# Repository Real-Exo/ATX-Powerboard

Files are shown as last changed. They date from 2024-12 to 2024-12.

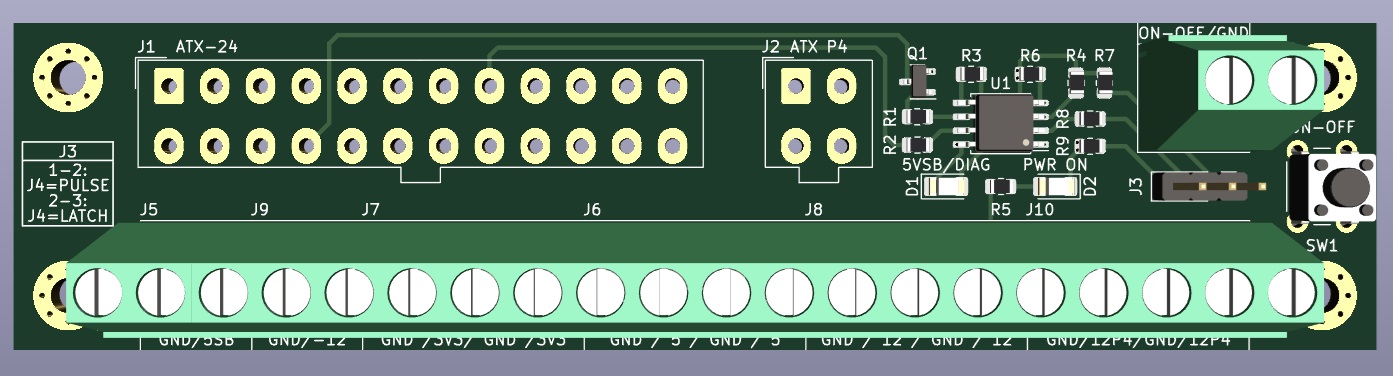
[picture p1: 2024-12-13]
ATX Powerboard/3D Render/ATX Powerboard.jpg

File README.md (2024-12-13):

A small board that allows controlling a standard ATX PC power supply in order to power other things. 
Onboard ON/OFF switch. External ON/OFF can be configured to be pulsed (push-button, for example) or latching (switch).
Do not change configuration jumper while board is running as that triggers a safety lockup (flashing diag LED).
Monitors PSU power good signal and turns PSU off when PWR_GOOD is not asserted, flashing diag LED.

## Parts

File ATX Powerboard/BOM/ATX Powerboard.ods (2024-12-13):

# | Reference | Qty | Value | Footprint | DNP | Partcode
1 | C1 | 1 | 100n | Capacitor_SMD:C_0805_2012Metric |  | CL21B104KBCNFNC
2 | D1, D2 | 2 | LED_Small | LED_SMD:LED_1206_3216Metric |  | 1206 SMD LED of choice, low current/high brightness
3 | J1 | 1 | ATX-24 | Connector_Molex:Molex_Mini-Fit_Jr_5566-24A_2x12_P4.20mm_Vertical |  | 39-28-1243 Molex
4 | J2 | 1 | ATX P4 | Connector_Molex:Molex_Mini-Fit_Jr_5566-04A_2x02_P4.20mm_Vertical |  | 39-28-1043 Molex
5 | J3 | 1 | M/L | Connector_PinHeader_2.54mm:PinHeader_1x03_P2.54mm_Vertical |  | Standard 2.54mm pin header
6 | J4 | 1 | ON/OFF | TerminalBlock_Phoenix:TerminalBlock_Phoenix_MKDS-1,5-2-5.08_1x02_P5.08mm_Horizontal |  | 1711767
7 | J5 | 1 | +5V STDBY | TerminalBlock_Phoenix:TerminalBlock_Phoenix_MKDS-1,5-2-5.08_1x02_P5.08mm_Horizontal |  | 1711767
8 | J6 | 1 | +5V | TerminalBlock_Phoenix:TerminalBlock_Phoenix_MKDS-1,5-4-5.08_1x04_P5.08mm_Horizontal |  | 2x 1711767
9 | J7 | 1 | +3V3 | TerminalBlock_Phoenix:TerminalBlock_Phoenix_MKDS-1,5-4-5.08_1x04_P5.08mm_Horizontal |  | 2x 1711767
10 | J8 | 1 | +12V | TerminalBlock_Phoenix:TerminalBlock_Phoenix_MKDS-1,5-4-5.08_1x04_P5.08mm_Horizontal |  | 2x 1711767
11 | J9 | 1 | -12V | TerminalBlock_Phoenix:TerminalBlock_Phoenix_MKDS-1,5-2-5.08_1x02_P5.08mm_Horizontal |  | 1711767
12 | J10 | 1 | +12V P4 | TerminalBlock_Phoenix:TerminalBlock_Phoenix_MKDS-1,5-4-5.08_1x04_P5.08mm_Horizontal |  | 2x 1711767
13 | Q1 | 1 | BSS138 | Package_TO_SOT_SMD:SOT-23 |  | BSS138
14 | R1, R2, R4, R5, R6, R7, R8, R9 | 8 | 10K | Resistor_SMD:R_0805_2012Metric |  | RK73B2ATTD103J
15 | R3 | 1 | 3K3 | Resistor_SMD:R_0805_2012Metric |  | RK73B2ATTD332J
16 | SW1 | 1 | ON/OFF | Button_Switch_THT:SW_PUSH_6mm_H5mm |  | PTS645SL502LFS
17 | U1 | 1 | PIC12C508A-ISM | Package_SO:SOIC-8_5.275x5.275mm_P1.27mm |  | PIC12C508A-04/SM

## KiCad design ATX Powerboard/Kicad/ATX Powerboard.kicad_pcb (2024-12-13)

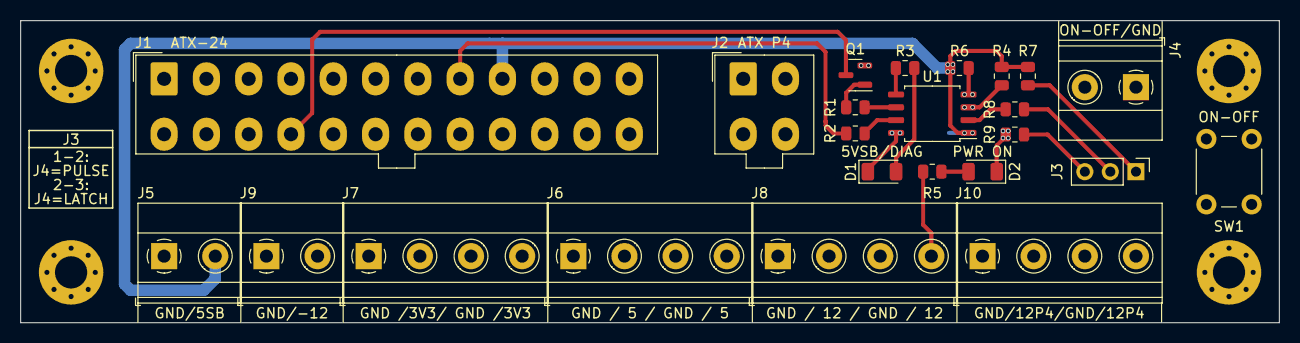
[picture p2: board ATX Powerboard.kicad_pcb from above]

Board: 4 copper layers, 125.0 x 30.0 mm, 25 parts (1 on the bottom side), 21 nets.

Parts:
C1: 100n; C_0805_2012Metric
D1: 5VSB/DIAG; LED_1206_3216Metric
D2: PWR ON; LED_1206_3216Metric
J1: ATX-24; Molex_Mini-Fit_Jr_5566-24A_2x12_P4.20mm_Vertical
J2: ATX P4; Molex_Mini-Fit_Jr_5566-04A_2x02_P4.20mm_Vertical
J3: M/L; PinHeader_1x03_P2.54mm_Vertical
J4: ON-OFF/GND; TerminalBlock_Phoenix_MKDS-1,5-2-5.08_1x02_P5.08mm_Horizont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
J5: GND/5SB; TerminalBlock_Phoenix_MKDS-1,5-2-5.08_1x02_P5.08mm_Horizont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
J6: GND / 5 / GND / 5; TerminalBlock_Phoenix_MKDS-1,5-4-5.08_1x04_P5.08mm_Horizont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
J7: GND /3V3/ GND /3V3; TerminalBlock_Phoenix_MKDS-1,5-4-5.08_1x04_P5.08mm_Horizont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
J8: GND / 12 / GND / 12; TerminalBlock_Phoenix_MKDS-1,5-4-5.08_1x04_P5.08mm_Horizont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
J9: GND/-12; TerminalBlock_Phoenix_MKDS-1,5-2-5.08_1x02_P5.08mm_Horizont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
J10: GND/12P4/GND/12P4; TerminalBlock_Phoenix_MKDS-1,5-4-5.08_1x04_P5.08mm_Horizont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
Q1: BSS138; SOT-23
R1, R2, R4, R5, R6, R7, R8, R9: 10K; R_0805_2012Metric
R3: 3K3; R_0805_2012Metric
SW1: ON-OFF; SW_PUSH_6mm_H5mm
U1: PIC12C508A-ISM; SOIC-8_5.275x5.275mm_P1.27mm

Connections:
+3V3: J1.1 (+3.3V), J1.2 (+3.3V), J1.12 (+3.3V), J1.13 (+3.3V), J7.2, J7.4
+5V: J1.4 (+5V), J1.6 (+5V), J1.21 (+5V), J1.22 (+5V), J1.23 (+5V), J6.2, J6.4
+5V STDBY: C1.1, J1.9 (+5VSB), J5.2, R4.1, R6.1, R7.1, U1.1 (VDD)
+12P: J2.3, J2.4, J10.2, J10.4
+12V: J1.10 (+12V), J1.11 (+12V), J8.2, J8.4, R5.1
-12V: J1.14 (-12V), J9.2
GND: C1.2, D1.1 (K), D2.1 (K), J1.3 (GND), J1.5 (GND), J1.7 (GND), J1.15 (GND), J1.17 (GND), J1.18 (GND), J1.19 (GND), J1.24 (GND), J2.1, J2.2, J4.1, J5.1, J6.1, J6.3, J7.1, J7.3, J8.1, J8.3, J9.1, J10.1, J10.3, Q1.2 (S), R9.1, SW1.2, U1.8 (VSS)
M/L: R8.1, U1.2 (GP5)
unnamed: D1.2 (A), R3.2
unnamed: D2.2 (A), R5.2
unnamed: J1.16 (PS_ON#), Q1.3 (D)
unnamed: J1.8 (PWR_OK), R2.1
unnamed: J3.1, R7.2
unnamed: J3.2, R8.2
unnamed: J3.3, R9.2
unnamed: Q1.1 (G), R1.2
unnamed: R3.1, U1.5 (GP2)
unnamed: R4.2, SW1.1, U1.3 (GP4)
ON/OFF: J4.2, R6.2, U1.4 (GP3)
PSON: R1.1, U1.6 (GP1)
PWROK: R2.2, U1.7 (GP0)

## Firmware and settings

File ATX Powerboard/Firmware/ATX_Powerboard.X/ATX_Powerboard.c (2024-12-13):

// CONFIG
#pragma config OSC = IntRC      // Oscillator selection bits (internal RC oscillator)
#pragma config WDT = OFF        // Watchdog timer enable bit (WDT disabled)
#pragma config CP = OFF         // Code protection bit (Code protection off)
#pragma config MCLRE = OFF      // MCLR enable bit (MCLR tied to VDD, (Internally))

// #pragma config statements should precede project file includes.
// Use project enums instead of #define for ON and OFF.

#include <xc.h>
#include <stdbool.h>
#include <stdint.h>

#define PWR_OK (1U << 0)
#define PS_ON (1U << 1)
#define LED (1U << 2)
#define EXT_ONOFF (1U << 3)
#define INT_ONOFF (1U << 4)
#define PULSE_OR_LATCH (1U << 5)
#define PWR_OK_MAX_FAILCOUNT 25

void
main(void)
{
    //CMCON = 7;
    //ANSEL = 0;
    
    OPTION = 0xC0;
    
    GPIO = LED;
    TRIS = ~(PS_ON | LED) & 0xFF;
    
    bool psuOn = false;
    bool isPulseNotLatch = GPIO & PULSE_OR_LATCH;
    bool wasPulseNotLatch = GPIO & PULSE_OR_LATCH;
    bool intOnOffWasPressed = false;
    bool intOnOffIsPressed = false;
    bool extOnOffWasPressed = false;
    bool extOnOffIsPressed = false;
    bool pwrOkFailed = false;
    uint8_t pwrOkFailCount = 0;
    
    while (1)
    {
        isPulseNotLatch = GPIO & PULSE_OR_LATCH;
        intOnOffIsPressed = !(GPIO & INT_ONOFF);
        extOnOffIsPressed = !(GPIO & EXT_ONOFF);
        
        if (isPulseNotLatch != wasPulseNotLatch)
        {
            while (1)
            {
                //Safety lockup, do not change jumper on the fly...
                GPIO &= ~PS_ON;
                GPIO ^= LED;
                __delay_ms(100);
            }
        }
        
        if (psuOn & !(GPIO & PWR_OK))
        {
            if (++pwrOkFailCount >= PWR_OK_MAX_FAILCOUNT)
            {
                pwrOkFailed = true;
                psuOn = false;
            }
        }
        
        if (psuOn)
        {           
            GPIO |= PS_ON;
        }
        else
        {
            GPIO &= ~PS_ON;
        }
        
        if (pwrOkFailed)
        {
            GPIO ^= LED;
            if ((intOnOffIsPressed != intOnOffWasPressed) 
            ||  (extOnOffIsPressed != extOnOffWasPressed))
            {
                pwrOkFailCount = 0;
                pwrOkFailed = false;
            }
        }
        else
        {
            GPIO |= LED;
            
            if (intOnOffIsPressed && !intOnOffWasPressed)
            {
                psuOn = !psuOn;
            }

            if (isPulseNotLatch)
            {
                if (extOnOffIsPressed && !extOnOffWasPressed)
                {
                    psuOn = !psuOn;
                }
            }
            else
            {
                if (extOnOffIsPressed && !extOnOffWasPressed)
                {
                    psuOn = true;
                }

                if (extOnOffWasPressed && !extOnOffIsPressed)
                {
                    psuOn = false;
                }
            }
        }
            
        wasPulseNotLatch = isPulseNotLatch;
        intOnOffWasPressed = intOnOffIsPressed;
        extOnOffWasPressed = extOnOffIsPressed;
                
        __delay_ms(100);
    }
}
